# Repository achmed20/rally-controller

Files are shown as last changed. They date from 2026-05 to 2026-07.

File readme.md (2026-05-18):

# Rally Controller

A DIY BLE gamepad controller for the DMD2 tablet, designed to mount on a 22mm handlebar. About 22.5mm wide. Built because proper rally controllers cost a fortune.

It appears to the host device as **"Rally Remote"** and simulates a standard gamepad over Bluetooth LE.

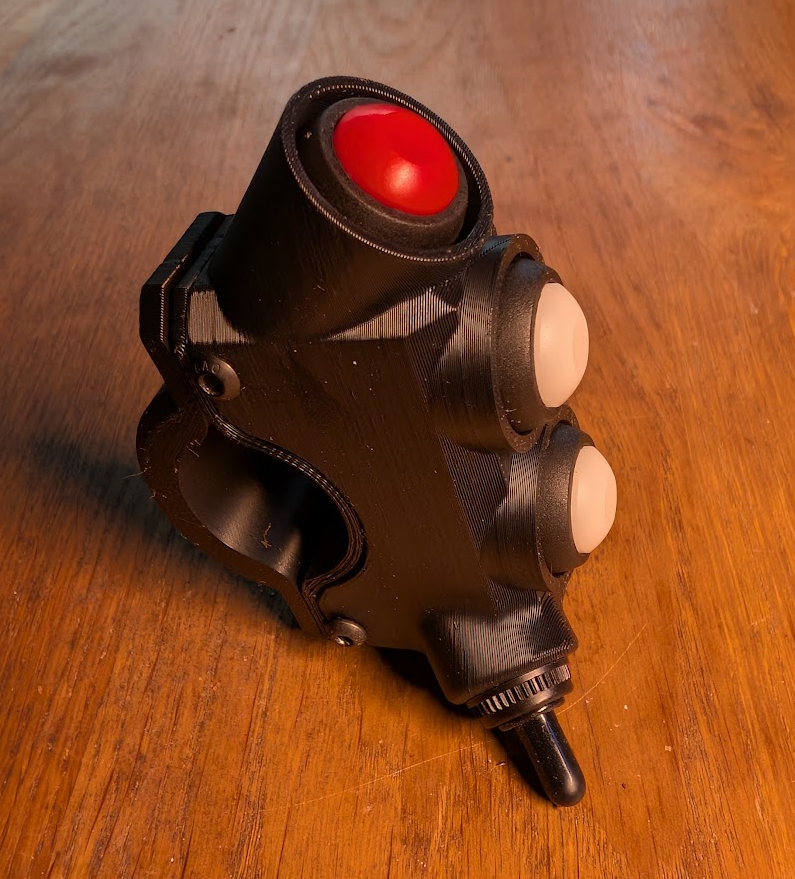
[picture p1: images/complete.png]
Rally Controller

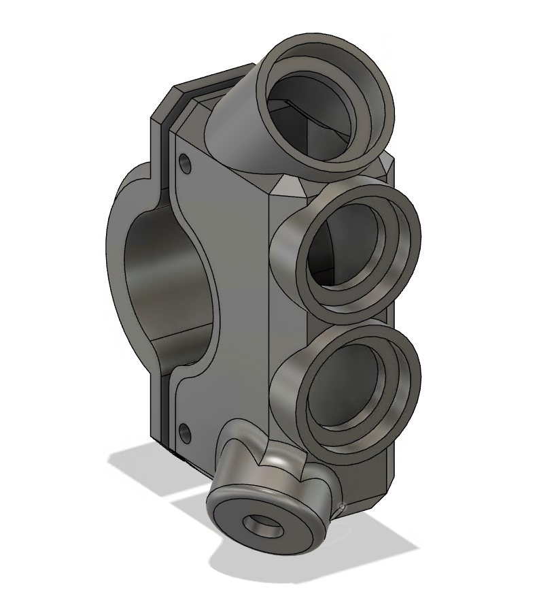
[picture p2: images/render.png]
Rally Controller object

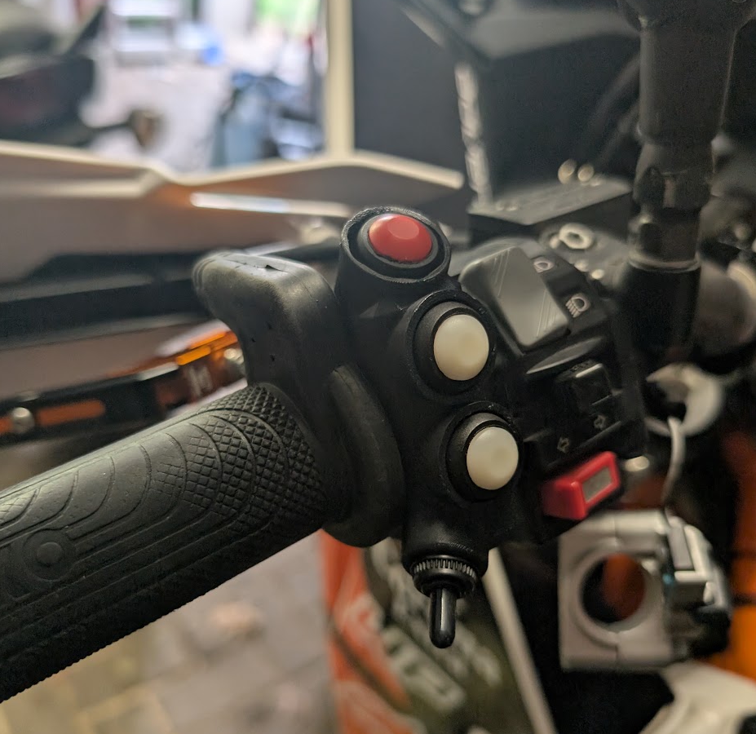
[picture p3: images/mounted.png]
Rally Controller mounted

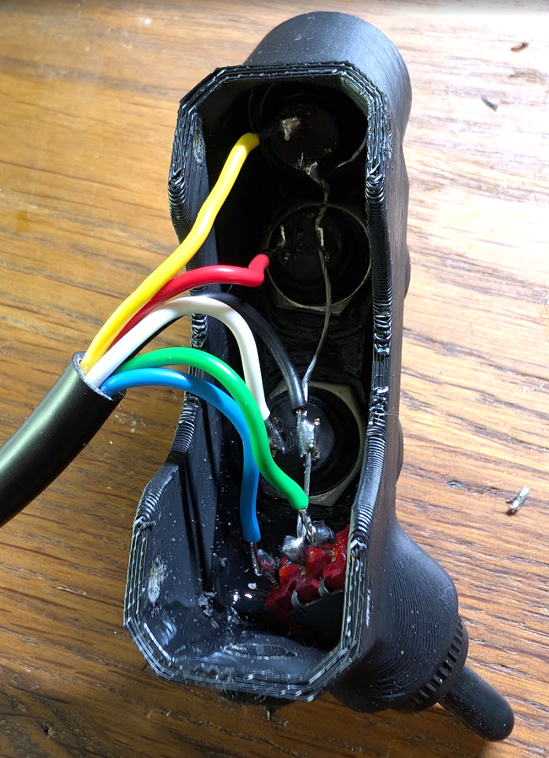
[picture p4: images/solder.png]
Rally Controller soldered


---

## Parts List

| Part | Qty |
|---|-----|
| PBS 33B M12 momentary button | 3 |
| MTS-123 2-way rocker switch | 1 |
| M3 x 6mm screws | 4 |
| M4 x 15mm screws | 2 |
| M4 nuts | 2 |
| ~50cm 6-core cable (as thin as possible) | 1 |
| Small zip tie | 1 |
| ESP32 with BLE support | 1 |

---

## 3D Printed Parts

STL files and the full 3MF project are in the [`3d models/`](3d%20models/) folder.
Use something Weather and heat proof like ASA or PETG

| File | Description |
|---|---|
| `remote base.stl` | Main housing |
| `remote backplate.stl` | Rear cover |
| `clamp.stl` | Handlebar clamp |
| `rally_remote_full.3mf` | Full assembly (all parts) |

---

## Assembly

1. Press-fit the M4 nuts into the backplate. If they're loose, secure with a drop of glue.
2. Install the buttons and tighten with their included nuts. Start with the top button, then the 2-way rocker, then the remaining buttons. Orient the terminals toward the outer walls to make soldering easier.
3. Use loctite or superglue to lock the nuts in place.
4. Strip a short piece of wire and solder a GND backbone — one terminal of each button connected to ground. This minimises the amount of individual wires you need.
5. Feed the 6-core cable through the housing and solder the remaining signal wires. If the whole is to tight, use a drill to extend the hole.
6. Secure the cable inside the case with a zip tie looped around the 6-core cable so it can't be pulled through easily.
7. Fit the backplate and secure with 4× M3×6mm screws.

---

## Pin Layout

All pins use the ESP32's internal pull-ups. Buttons connect the pin to GND when pressed. Solder them accordingly. Rmember to solder the bacbone (the stripped wire) to GND and not to 3.3V.

| GPIO | Function |
|---|---|
| 25 | Forward (rocker) |
| 26 | Backwards (rocker) |
| 32 | Button 1 |
| 33 | Button 2 |
| 27 | Button 3 (multi-press) |

To use Pins, change the `#define PIN_*` values at the top of [`src/main.cpp`](src/main.cpp) but make sure they support internal pullups.

---

## Button Mapping

| Input | Gamepad output |
|---|---|
| Forward rocker | Hat right |
| Backwards rocker | Hat left |
| Button 1 | A (Button 1) |
| Button 2 | B (Button 2) |
| Button 3 — 1× press | X (Button 3) |
| Button 3 — 2× press | Y (Button 4) |
| Button 3 — 3× press | LB (Button 5) |
| Button 3 — long press | RB (Button 6) |

Multi-press window is 400 ms. Long press threshold is 2000 ms.

> **Pairing mode:** Hold Button 3 for 15 seconds to restart BLE advertising and make the device discoverable again.

---

## Software / Build

### Requirements

- [PlatformIO](https://platformio.org/) (VS Code extension or CLI)
- ESP32 board support (`espressif32` platform)
- Library: [`lemmingdev/ESP32-BLE-Gamepad`](https://github.com/lemmingDEV/ESP32-BLE-Gamepad) — installed automatically by PlatformIO

### Build & Flash

```bash
# Build
pio run

# Build and upload
pio run --target upload

# Monitor serial output (115200 baud)
pio device monitor
```

Or use the PlatformIO sidebar in VS Code (Build / Upload / Monitor buttons).

The [`platformio.ini`](platformio.ini) targets the `esp32dev` board. Change the `board` value there if you're using a different variant (e.g. `lolin32`, `esp32-s3-devkitc-1`).

### First Run / Pairing

1. Flash the firmware.
2. If the device doesn't show up on your phone/tablet, reboot the controller after flashing.
3. Pair it like any Bluetooth gamepad — it will appear as **"Rally Remote"**.
4. If you need to re-pair, hold Button 3 for 15 seconds to re-enter advertising mode.

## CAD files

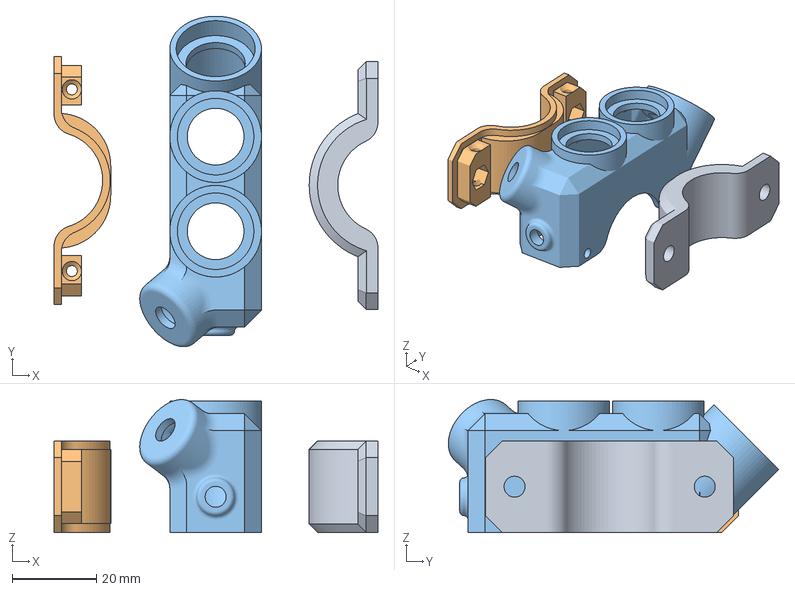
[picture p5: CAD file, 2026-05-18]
3d models/rally_remote_full.3mf
77.1 x 78.6 x 31.6 mm
clamp.stl
remote backplate.stl
remote base.stl

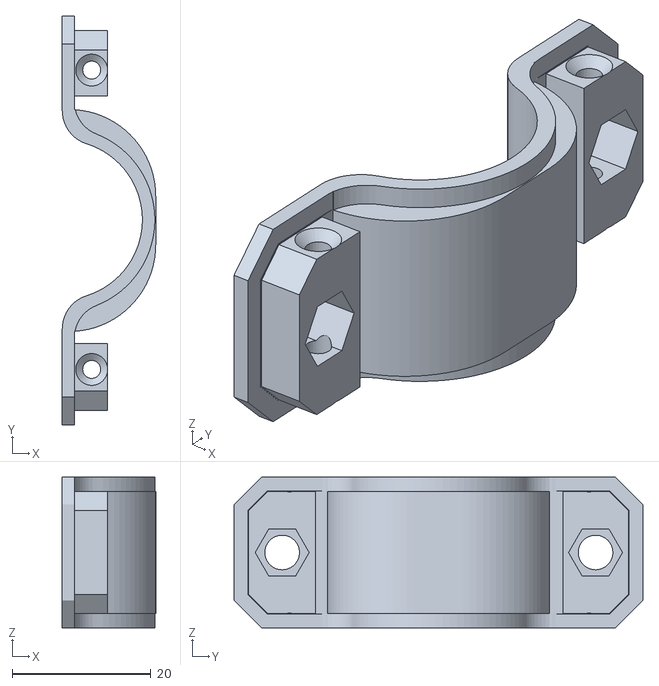
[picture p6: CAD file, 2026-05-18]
3d models/remote backplate.stl
13.5 x 59.0 x 21.8

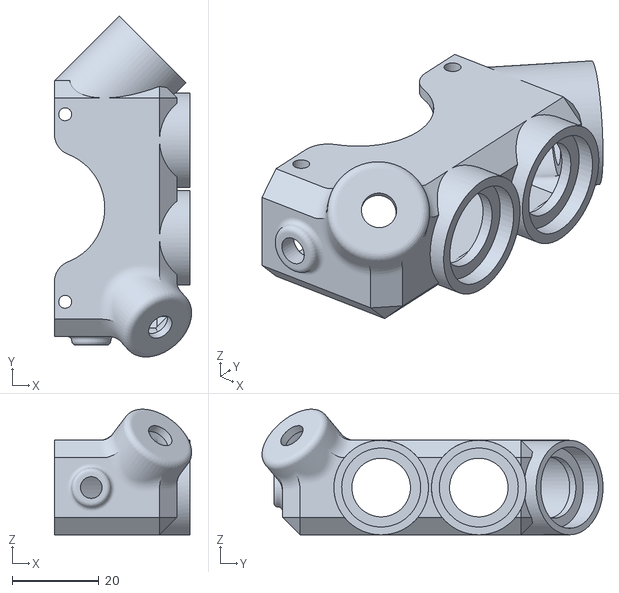
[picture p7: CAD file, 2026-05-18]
3d models/remote base.stl
31.6 x 78.6 x 29.0

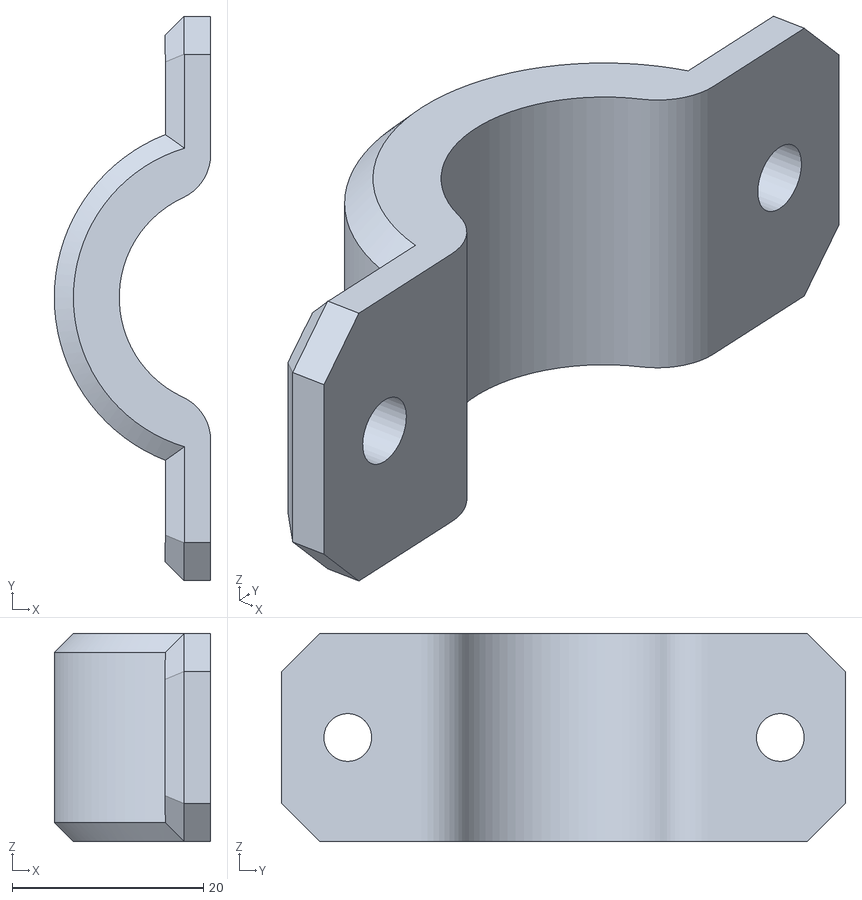
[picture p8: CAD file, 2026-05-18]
3d models/clamp.stl
16.4 x 59.0 x 21.8

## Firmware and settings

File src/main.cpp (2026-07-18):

#include <Arduino.h>
#include <BleGamepad.h>

// --- Pin Definitions ---
// All pins support internal pull-ups. Buttons connect pin to GND.
#define PIN_FORWARD   5
#define PIN_BACKWARDS 4
#define PIN_BUTTON1   2
#define PIN_BUTTON2   3
#define PIN_BUTTON3   6

// --- Configuration ---
#define DEBOUNCE_MS        50
#define PAIRING_HOLD_MS    15000  // 15 seconds hold for pairing mode
#define RECONNECT_DELAY_MS 5000   // Wait before restarting BLE after disconnect
#define MULTI_PRESS_MS     400    // Max time between presses for multi-press detection
#define LONG_PRESS_MS      2000   // Long press threshold for Button 3
#define BUTTON3_MULTIPRESS 0          // 1 = multi/long press detection, 0 = simple button

// --- Gamepad Button Mappings ---
// Change these to remap buttons to different gamepad buttons (1-indexed)
#define GAMEPAD_BTN_BUTTON1       BUTTON_1   // A
#define GAMEPAD_BTN_BUTTON2       BUTTON_2   // B
#define GAMEPAD_BTN_BUTTON3_1X    BUTTON_3   // X  (single press)
#define GAMEPAD_BTN_BUTTON3_2X    BUTTON_4   // Y  (double press)
#define GAMEPAD_BTN_BUTTON3_3X    BUTTON_5   // LB (triple press)
#define GAMEPAD_BTN_BUTTON3_LONG  BUTTON_6   // RB (long press)

// Hat switch directions for Forward/Backwards
#define HAT_FORWARD   HAT_RIGHT
#define HAT_BACKWARDS HAT_LEFT

// --- BLE Gamepad ---
BleGamepad bleGamepad("Rally Remote", "DIY Rally Controller", 100);

// --- Button State ---
struct Button {
  uint8_t pin;
  bool lastState;
  bool currentState;
  unsigned long lastDebounceTime;
  unsigned long pressStartTime;
  bool pressed;
};

Button buttons[] = {
  {PIN_FORWARD,   HIGH, HIGH, 0, 0, false},
  {PIN_BACKWARDS, HIGH, HIGH, 0, 0, false},
  {PIN_BUTTON1,   HIGH, HIGH, 0, 0, false},
  {PIN_BUTTON2,   HIGH, HIGH, 0, 0, false},
  {PIN_BUTTON3,   HIGH, HIGH, 0, 0, false},
};

#define NUM_BUTTONS (sizeof(buttons) / sizeof(buttons[0]))
#define BTN_IDX_FORWARD   0
#define BTN_IDX_BACKWARDS 1
#define BTN_IDX_BUTTON1   2
#define BTN_IDX_BUTTON2   3
#define BTN_IDX_BUTTON3   4

bool pairingTriggered = false;

// --- Functions ---
void updateButton(Button &btn) {
  bool reading = digitalRead(btn.pin);

  if (reading != btn.lastState) {
    btn.lastDebounceTime = millis();
  }

  if ((millis() - btn.lastDebounceTime) > DEBOUNCE_MS) {
    if (reading != btn.currentState) {
      btn.currentState = reading;
      // Button is active LOW (pressed = connected to GND)
      btn.pressed = (btn.currentState == LOW);

      if (btn.pressed) {
        btn.pressStartTime = millis();
      }
    }
  }

  btn.lastState = reading;
}

void enterPairingMode() {
  Serial.println("Entering pairing mode...");
  bleGamepad.end();
  delay(500);
  BleGamepadConfiguration config;
  config.setButtonCount(6);
  config.setHatSwitchCount(1);
  config.setAutoReport(false);
  bleGamepad.begin(&config);
  Serial.println("Pairing mode active. Device is discoverable.");
}

void setup() {
  Serial.begin(115200);
  delay(1000);  // Wait for serial monitor to connect

  Serial.println("================================");
  Serial.println("  Rally Controller v2.0");
  Serial.println("  BLE HID Gamepad Device");
  Serial.println("================================");
  Serial.println();
  Serial.println("Pin configuration (all INPUT_PULLUP, buttons to GND):");
  Serial.printf("  Forward:   GPIO %d\n", PIN_FORWARD);
  Serial.printf("  Backwards: GPIO %d\n", PIN_BACKWARDS);
  Serial.printf("  Button 1:  GPIO %d\n", PIN_BUTTON1);
  Serial.printf("  Button 2:  GPIO %d\n", PIN_BUTTON2);
  Serial.printf("  Button 3:  GPIO %d\n", PIN_BUTTON3);
  Serial.println();

  // Configure button pins - all use internal pull-ups
  pinMode(PIN_FORWARD,   INPUT_PULLUP);
  pinMode(PIN_BACKWARDS, INPUT_PULLUP);
  pinMode(PIN_BUTTON1,   INPUT_PULLUP);
  pinMode(PIN_BUTTON2,   INPUT_PULLUP);
  pinMode(PIN_BUTTON3,   INPUT_PULLUP);

  Serial.println("Starting BLE Gamepad...");
  BleGamepadConfiguration config;
  config.setButtonCount(6);
  config.setHatSwitchCount(1);
  config.setAutoReport(false);
  bleGamepad.begin(&config);
  Serial.println("BLE Gamepad started. Waiting for connection...");
  Serial.printf("Hold Button 3 for %d seconds to enter pairing mode.\n", PAIRING_HOLD_MS / 1000);
  Serial.println();
}

void loop() {
  // Update all button states
  for (size_t i = 0; i < NUM_BUTTONS; i++) {
    updateButton(buttons[i]);
  }

  // --- Check Button 3 for pairing mode (10s hold) ---
  if (buttons[BTN_IDX_BUTTON3].pressed) {
    unsigned long holdTime = millis() - buttons[BTN_IDX_BUTTON3].pressStartTime;
    if (holdTime >= PAIRING_HOLD_MS && !pairingTriggered) {
      pairingTriggered = true;
      enterPairingMode();
    }
  } else {
    pairingTriggered = false;
  }

  // --- Connection status tracking and reconnection ---
  static bool wasConnected = false;
  static unsigned long disconnectTime = 0;
  static bool reconnecting = false;
  bool isConnected = bleGamepad.isConnected();

  if (isConnected && !wasConnected) {
    Serial.println("[BLE] Device connected!");
    reconnecting = false;
  } else if (!isConnected && wasConnected) {
    Serial.println("[BLE] Device disconnected. Will restart BLE in 5s...");
    disconnectTime = millis();
    reconnecting = false;
  }

  // Restart BLE after disconnect to ensure it re-advertises properly
  if (!isConnected && !reconnecting && wasConnected == false && disconnectTime > 0) {
    if (millis() - disconnectTime >= RECONNECT_DELAY_MS) {
      Serial.println("[BLE] Restarting BLE to re-advertise...");
      bleGamepad.end();
      delay(500);
      BleGamepadConfiguration config;
      config.setButtonCount(6);
      config.setHatSwitchCount(1);
      config.setAutoReport(false);
      bleGamepad.begin(&config);
      Serial.println("[BLE] BLE restarted. Waiting for connection...");
      reconnecting = true;
      disconnectTime = 0;
    }
  }

  wasConnected = isConnected;

  // --- Handle button presses (only when connected) ---
  if (isConnected) {
    bool reportNeeded = false;

    // Forward button -> Hat switch right
    static bool fwdHeld = false;
    if (buttons[BTN_IDX_FORWARD].pressed && !fwdHeld) {
      Serial.println("[BTN] Forward pressed");
      bleGamepad.setHat1(HAT_FORWARD);
      fwdHeld = true;
      reportNeeded = true;
    } else if (!buttons[BTN_IDX_FORWARD].pressed && fwdHeld) {
      Serial.println("[BTN] Forward released");
      // Only release hat if backwards isn't held
      if (!buttons[BTN_IDX_BACKWARDS].pressed) {
        bleGamepad.setHat1(HAT_CENTERED);
      }
      fwdHeld = false;
      reportNeeded = true;
    }

    // Backwards button -> Hat switch left
    static bool bwdHeld = false;
    if (buttons[BTN_IDX_BACKWARDS].pressed && !bwdHeld) {
      Serial.println("[BTN] Backwards pressed");
      bleGamepad.setHat1(HAT_BACKWARDS);
      bwdHeld = true;
      reportNeeded = true;
    } else if (!buttons[BTN_IDX_BACKWARDS].pressed && bwdHeld) {
      Serial.println("[BTN] Backwards released");
      // Only release hat if forward isn't held
      if (!buttons[BTN_IDX_FORWARD].pressed) {
        bleGamepad.setHat1(HAT_CENTERED);
      }
      bwdHeld = false;
      reportNeeded = true;
    }

    // Button 1
    static bool btn1Held = false;
    if (buttons[BTN_IDX_BUTTON1].pressed && !btn1Held) {
      Serial.println("[BTN] Button 1 pressed");
      bleGamepad.press(GAMEPAD_BTN_BUTTON1);
      btn1Held = true;
      reportNeeded = true;
    } else if (!buttons[BTN_IDX_BUTTON1].pressed && btn1Held) {
      Serial.println("[BTN] Button 1 released");
      bleGamepad.release(GAMEPAD_BTN_BUTTON1);
      btn1Held = false;
      reportNeeded = true;
    }

    // Button 2
    static bool btn2Held = false;
    if (buttons[BTN_IDX_BUTTON2].pressed && !btn2Held) {
      Serial.println("[BTN] Button 2 pressed");
      bleGamepad.press(GAMEPAD_BTN_BUTTON2);
      btn2Held = true;
      reportNeeded = true;
    } else if (!buttons[BTN_IDX_BUTTON2].pressed && btn2Held) {
      Serial.println("[BTN] Button 2 released");
      bleGamepad.release(GAMEPAD_BTN_BUTTON2);
      btn2Held = false;
      reportNeeded = true;
    }

#if BUTTON3_MULTIPRESS
    // Button 3 - multi-press (only if pairing not triggered)
    static uint8_t btn3TapCount = 0;
    static unsigned long btn3LastTapTime = 0;
    static bool btn3WasPressed = false;
    static bool btn3LongPressSent = false;

    if (buttons[BTN_IDX_BUTTON3].pressed && !btn3WasPressed && !pairingTriggered) {
      btn3WasPressed = true;
      btn3LongPressSent = false;
      btn3TapCount++;
      btn3LastTapTime = millis();
      Serial.printf("[BTN] Button 3 tap %d\n", btn3TapCount);
    } else if (!buttons[BTN_IDX_BUTTON3].pressed && btn3WasPressed) {
      btn3WasPressed = false;
    }

    // Long press detection
    if (buttons[BTN_IDX_BUTTON3].pressed && btn3WasPressed && !btn3LongPressSent && !pairingTriggered) {
      unsigned long holdTime = millis() - buttons[BTN_IDX_BUTTON3].pressStartTime;
      if (holdTime >= LONG_PRESS_MS) {
        Serial.println("[BTN] Button 3 long press -> Gamepad Button 6");
        bleGamepad.press(GAMEPAD_BTN_BUTTON3_LONG);
        bleGamepad.sendReport();
        delay(50);
        bleGamepad.release(GAMEPAD_BTN_BUTTON3_LONG);
        bleGamepad.sendReport();
        btn3LongPressSent = true;
        btn3TapCount = 0;  // Cancel multi-tap
      }
    }

    // Fire multi-tap action after window expires (only if no long press)
    if (btn3TapCount > 0 && !btn3WasPressed && !btn3LongPressSent &&
        (millis() - btn3LastTapTime) >= MULTI_PRESS_MS) {
      uint8_t btn;
      switch (btn3TapCount) {
        case 1:  btn = GAMEPAD_BTN_BUTTON3_1X; break;
        case 2:  btn = GAMEPAD_BTN_BUTTON3_2X; break;
        default: btn = GAMEPAD_BTN_BUTTON3_3X; break;
      }
      Serial.printf("[BTN] Button 3 %dx -> Gamepad Button %d\n", btn3TapCount, btn);
      bleGamepad.press(btn);
      bleGamepad.sendReport();
      delay(50);
      bleGamepad.release(btn);
      reportNeeded = true;
      btn3TapCount = 0;
    }
#else
    // Button 3 - simple press
    static bool btn3Held = false;
    if (buttons[BTN_IDX_BUTTON3].pressed && !btn3Held && !pairingTriggered) {
      Serial.println("[BTN] Button 3 pressed");
      bleGamepad.press(GAMEPAD_BTN_BUTTON3_1X);
      btn3Held = true;
      reportNeeded = true;
    } else if (!buttons[BTN_IDX_BUTTON3].pressed && btn3Held) {
      Serial.println("[BTN] Button 3 released");
      bleGamepad.release(GAMEPAD_BTN_BUTTON3_1X);
      btn3Held = false;
      reportNeeded = true;
    }
#endif

    if (reportNeeded) {
      bleGamepad.sendReport();
    }
  } else {
    // Release all buttons if we lose connection
    bleGamepad.resetButtons();
  }

  // Yield more time to BLE stack when not connected
  if (isConnected) {
    delay(10);
  } else {
    delay(100);
  }
}

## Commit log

2026-05-11 Add initial project structure with configuration files and documentation
    - Create .gitignore to exclude build artifacts and IDE settings
    - Add extensions.json for recommended VSCode extensions
    - Include README files for header files, libraries, and tests
    - Set up platformio.ini for ESP32 development with library dependencies
    - Implement main.cpp for Bluetooth HID functionality with button mappings
2026-05-18 Add 3D models and update README with assembly instructions and parts list
    [clamp.stl, rally_remote_full.3mf, remote backplate.stl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]
2026-05-18 Update README with assembly instructions and material recommendations
2026-07-18 Update platformio.ini and main.cpp with correct board settings and pin definitions. made multibutton mapping optional
    [main.cpp]
2026-07-18 Swap pin definitions for forward and backwards controls in main.cpp
    [main.cpp]
